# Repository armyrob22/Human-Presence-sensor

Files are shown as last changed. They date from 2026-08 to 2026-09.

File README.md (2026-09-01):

# Human-Presence-sensor
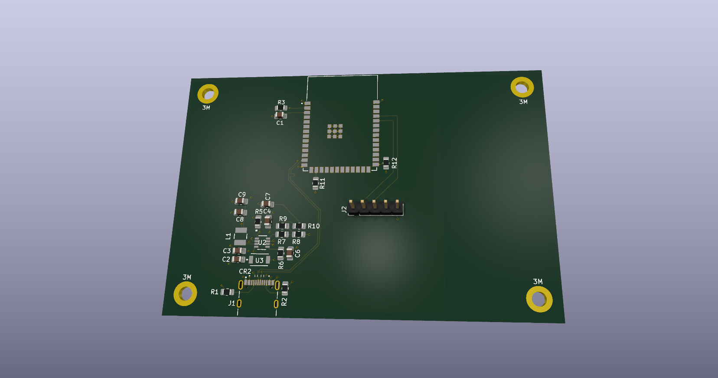
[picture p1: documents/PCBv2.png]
assembled board v2

This is my second version of this board. My first board had many errors and was basically unusable. The pin headers were not aligned once i got the boards. This made it impossible to use the esp32 dev board I had. The biggest failure was the fact that i misplaced the USB type C connector. It was not close enough to the edge for me to plug in a power cable. This design puts the ESP32 on the PCB and lets just the mmWave 24Ghz radar board plug into a pin header. This design forced me to learn how to really design a buck converter circuit so i can take the 5V USB input power and drop it down to 3.3V required for the MCU. I took it a step further and I really drilled down on learning the physic's and the equations to derive what you need for a buck converter.

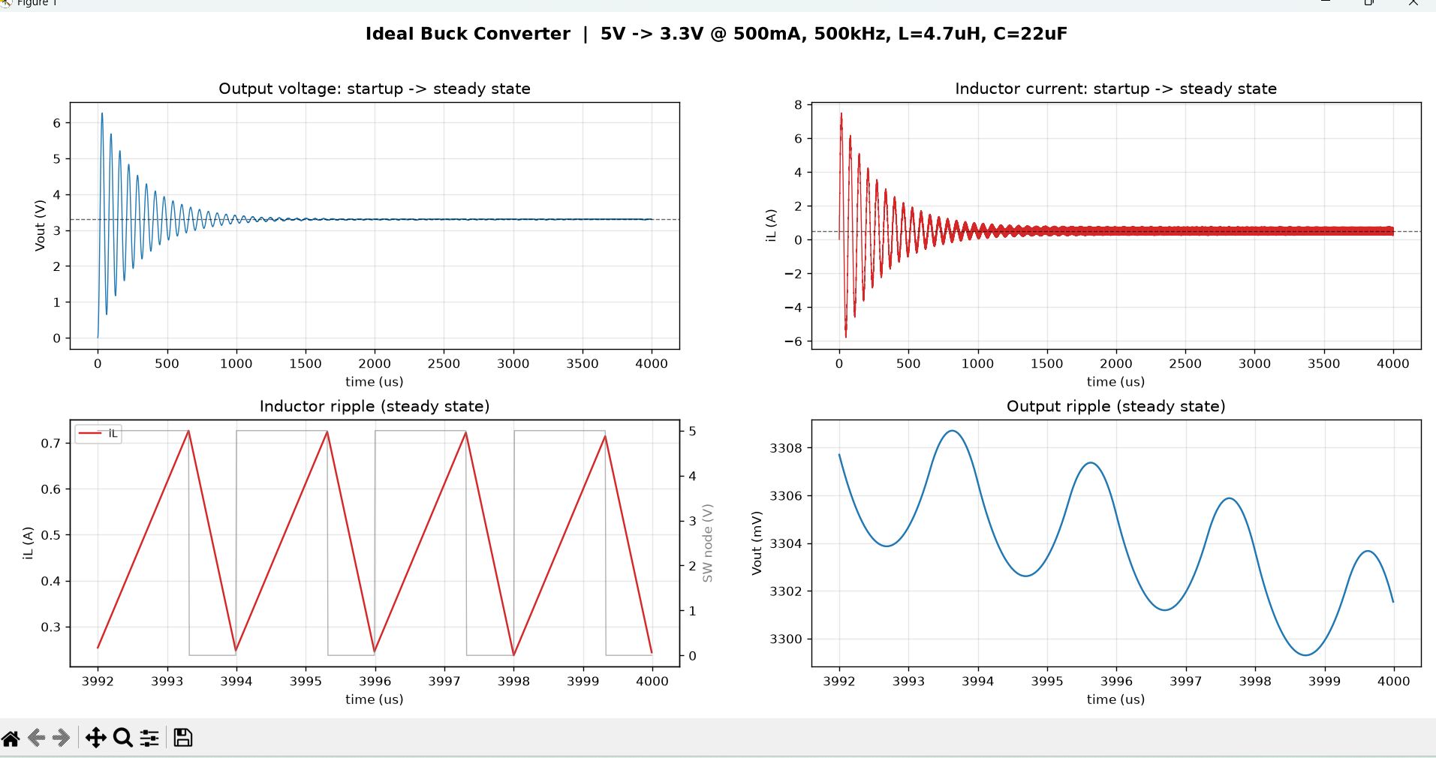
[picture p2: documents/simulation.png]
python simulation

This is the result of my python script running a simulation of my chosen buck converter. I ran several different versions to see if my inductor sizing was correct. The reference design I used for most of my layout turned out to be really good for my given circuit. This is why i chose a 4.7uH inductor for my design. Even though this is my project and my own board I tried to treat it with the same care I will bring to the work place when I get to design other boards. The next big piece of the buck converter was to figure out the feedback sense resistor values required. My converter has a reference voltage of 0.8v. This means the formula I used is
Vout = Vref × (1 + R1/R2)
Vref = 0.8V, R2 = 12.7k, R1 = 40.2k
Vout = 0.8 × (1 + 40.2/12.7) = 3.33V
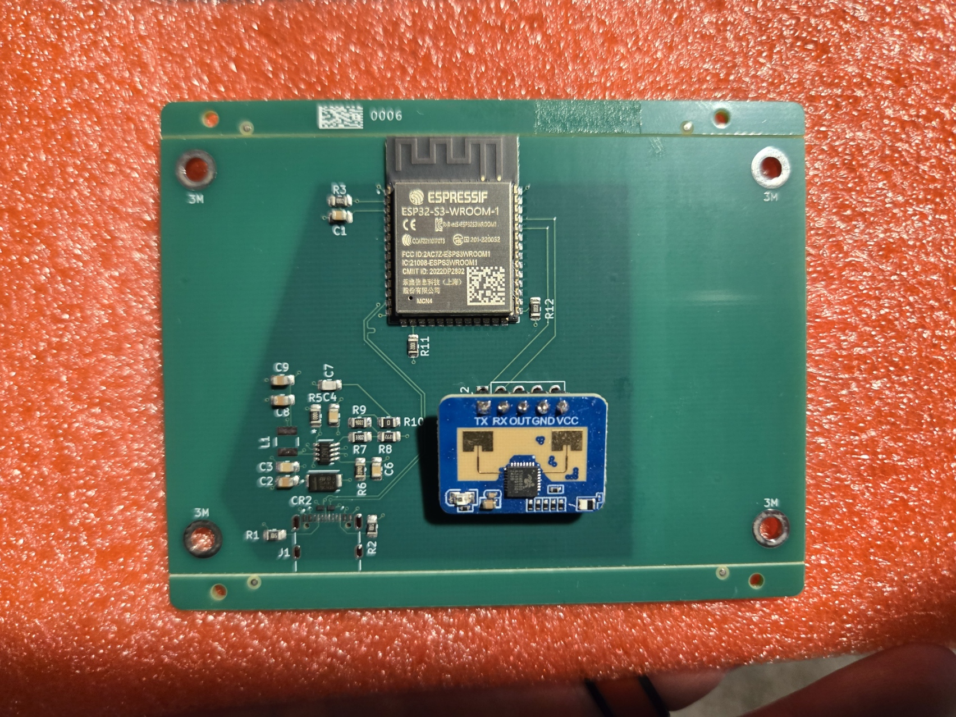
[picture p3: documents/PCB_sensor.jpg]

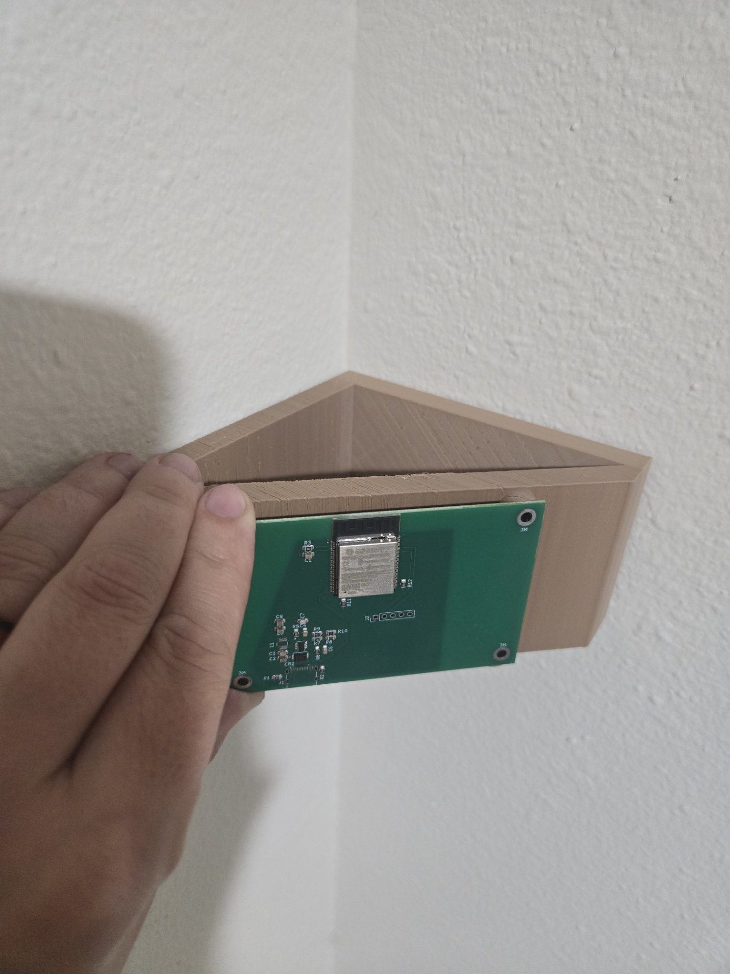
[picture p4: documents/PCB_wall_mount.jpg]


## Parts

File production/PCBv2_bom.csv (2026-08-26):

Designator | Footprint | Quantity | Value | LCSC Part #
C1 | 0805 | 1 | 1uF
C2, C8, C9 | 0805 | 3 | 22uF
C3, C4, C6 | 0805 | 3 | 0.1uF
C7 | 0805 | 1 | 33pF
CR1, CR2 | CR_RCLAMP053_1XP6_SEM-L | 2 | RCLAMP0531TQTCT
J1 | SAMESKY_UJ20-C-H-G-SMT-1-P16-TR | 1 | UJ20-C-H-G-SMT-1-P16-TR
J2 | PinHeader_1x05_P2.54mm_Vertical | 1 | Conn_01x05_Pin
L1 | IND_DFE322520FD-4R7M=P2_MUR | 1 | 4.7uH
R1, R2 | 0805 | 2 | 5k1
R10 | 0805 | 1 | 0
R11, R12, R3 | 0805 | 3 | 10k
R5 | 0805 | 1 | 100k
R6 | 0805 | 1 | 20
R7 | 0805 | 1 | 33k
R8 | 0805 | 1 | 12k7
R9 | 0805 | 1 | 40k2
U1 | XCVR_ESP32-S3-WROOM-1-N4 | 1 | ESP32-S3-WROOM-1-N4
U2 | TSOT23-8_MPS | 1 | MP2315GJ-Z
U3 | SOD128_STM-L | 1 | SM6F6.0AY

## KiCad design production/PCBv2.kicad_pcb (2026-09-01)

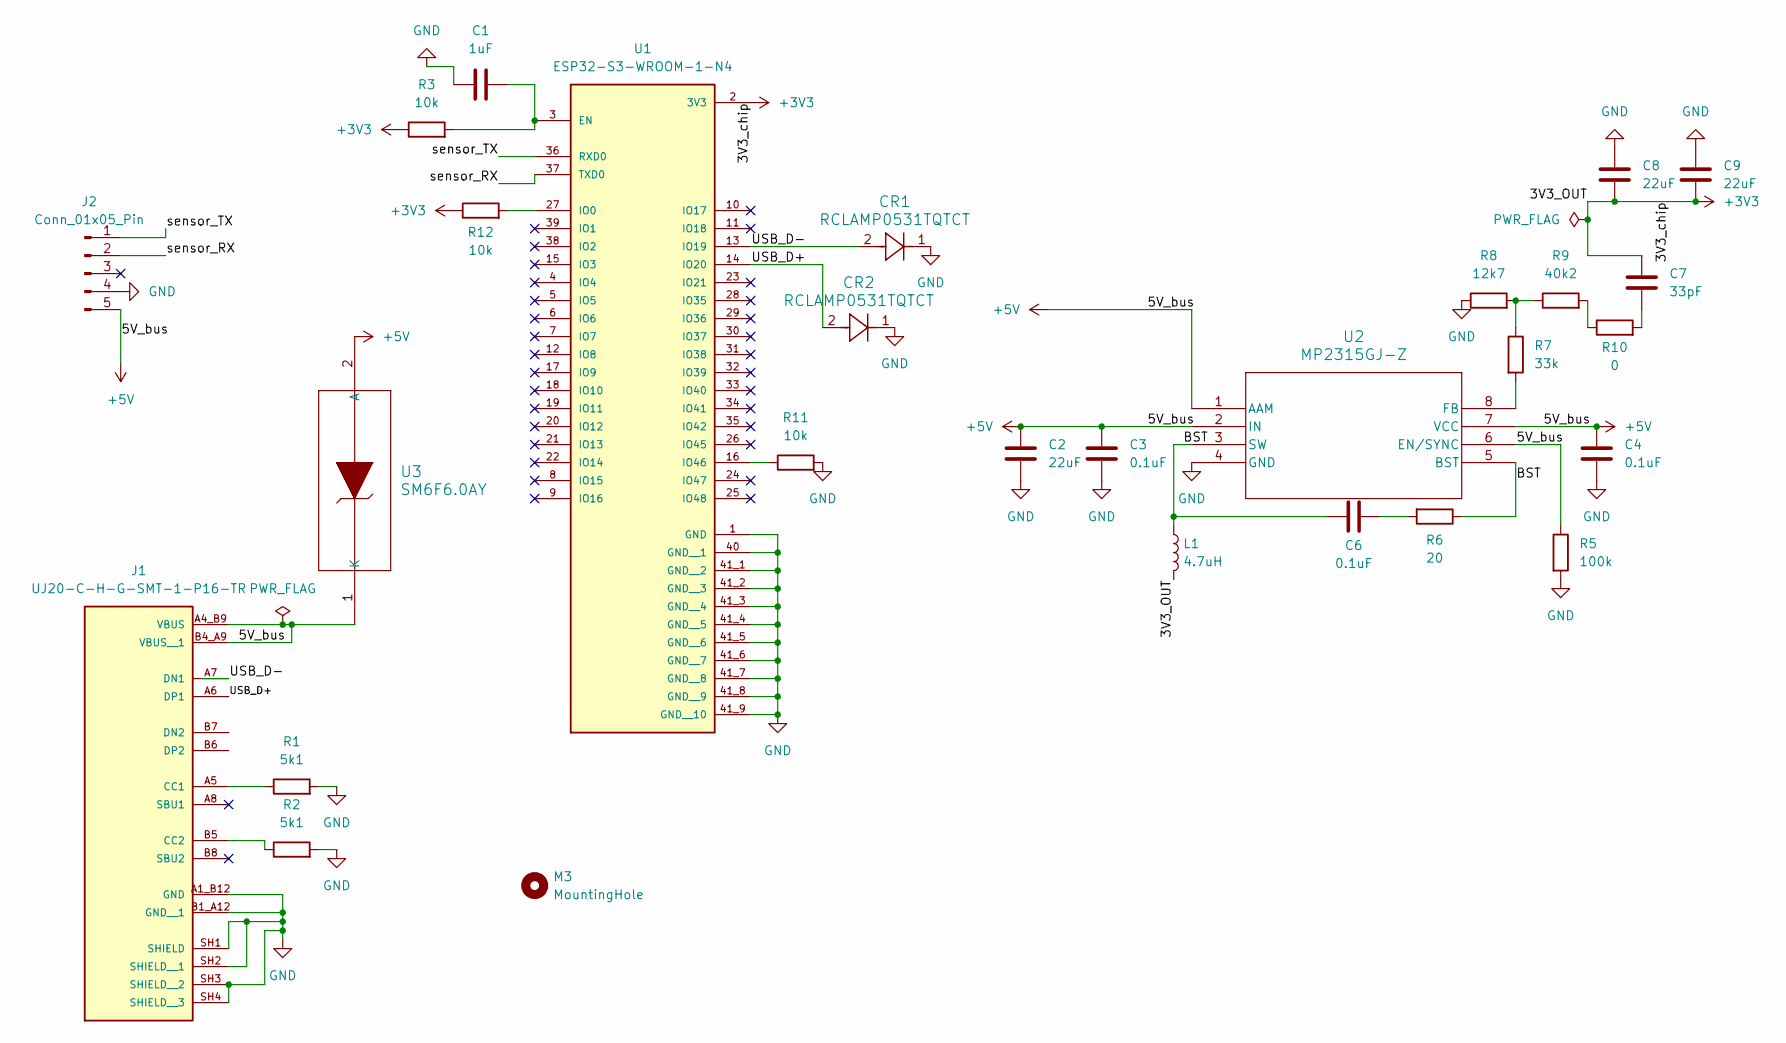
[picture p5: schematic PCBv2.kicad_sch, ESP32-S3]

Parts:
C1: 1uF; C_0805_2012Metric_Pad1.18x1.45mm_HandSolder
C2, C8, C9: 22uF; C_0805_2012Metric_Pad1.18x1.45mm_HandSolder
C3, C4, C6: 0.1uF; C_0805_2012Metric_Pad1.18x1.45mm_HandSolder
C7: 33pF; C_0805_2012Metric_Pad1.18x1.45mm_HandSolder
CR1, CR2: RCLAMP0531TQTCT; CR_RCLAMP053_1XP6_SEM-L
J1: UJ20-C-H-G-SMT-1-P16-TR; SAMESKY_UJ20-C-H-G-SMT-1-P16-TR; PARTREV 1.0
J2: Conn_01x05_Pin; PinHeader_1x05_P2.54mm_Vertical
L1: 4.7uH; IND_DFE322520FD-4R7M=P2_MUR
M3: MountingHole; MountingHole_3.2mm_M3_DIN965_Pad
R1, R2: 5k1; R_0805_2012Metric_Pad1.20x1.40mm_HandSolder
R3, R11, R12: 10k; R_0805_2012Metric_Pad1.20x1.40mm_HandSolder
R5: 100k; R_0805_2012Metric_Pad1.20x1.40mm_HandSolder
R6: 20; R_0805_2012Metric_Pad1.20x1.40mm_HandSolder
R7: 33k; R_0805_2012Metric_Pad1.20x1.40mm_HandSolder
R8: 12k7; R_0805_2012Metric_Pad1.20x1.40mm_HandSolder
R9: 40k2; R_0805_2012Metric_Pad1.20x1.40mm_HandSolder
R10: 0; R_0805_2012Metric_Pad1.20x1.40mm_HandSolder
U1: ESP32-S3-WROOM-1-N4; XCVR_ESP32-S3-WROOM-1-N4; PARTREV v1.0
U2: MP2315GJ-Z; TSOT23-8_MPS
U3: SM6F6.0AY; SOD128_STM-L

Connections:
+3V3: C7.2, C8.1, C9.1, L1.2, R3.1, R12.1, U1.2 (3V3)
+5V: C2.2, C3.2, C4.1, J1.A4_B9 (VBUS), J1.B4_A9 (VBUS__1), J2.5, R5.1, U2.1 (AAM), U2.2 (IN), U2.6 (EN/SYNC), U2.7 (VCC), U3.1 (K), U3.2 (A)
/BST: C6.1, L1.1, R6.1, U2.3 (SW), U2.5 (BST)
/USB_D+: CR2.2, J1.A6 (DP1), U1.14 (IO20)
/USB_D-: CR1.2, J1.A7 (DN1), U1.13 (IO19)
/sensor_RX: J2.2, U1.37 (TXD0)
/sensor_TX: J2.1, U1.36 (RXD0)
GND: C1.1, C2.1, C3.1, C4.2, C8.2, C9.2, CR1.1, CR2.1, J1.A1_B12 (GND), J1.B1_A12 (GND__1), J1.SH1 (SHIELD), J1.SH2 (SHIELD__1), J1.SH3 (SHIELD__2), J1.SH4 (SHIELD__3), J2.4, R1.2, R2.2, R5.2, R8.1, R11.2, U1.1 (GND), U1.40 (GND__1), U1.41_1 (GND__2), U1.41_2 (GND__3), U1.41_3 (GND__4), U1.41_4 (GND__5), U1.41_5 (GND__6), U1.41_6 (GND__7), U1.41_7 (GND__8), U1.41_8 (GND__9), U1.41_9 (GND__10), U1.41_10, U1.41_11, U1.41_12, U1.41_13, U1.41_14, U1.41_15, U1.41_16, U1.41_17, U1.41_18, U1.41_19, U1.41_20, U1.41_21, U2.4 (GND)
unnamed: C6.2, R6.2
unnamed: C7.1, R10.2
unnamed: J1.A5 (CC1), R1.1
unnamed: J1.B5 (CC2), R2.1
unnamed: R7.1, R8.2, R9.1
unnamed: R9.2, R10.1
unnamed: C1.2, R3.2, U1.3 (EN)
unnamed: R12.2, U1.27 (IO0)
unnamed: R11.1, U1.16 (IO46)
unnamed: R7.2, U2.8 (FB)

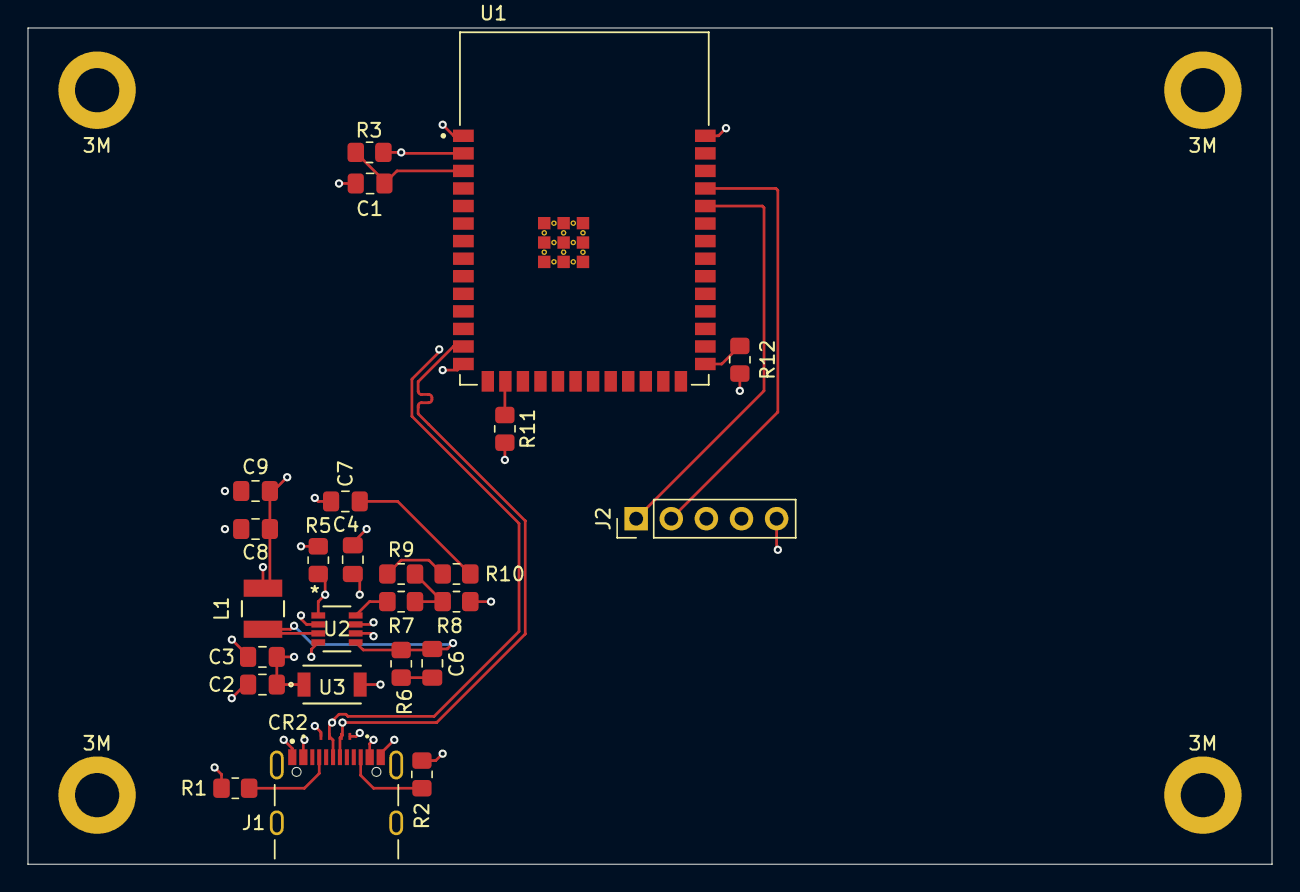
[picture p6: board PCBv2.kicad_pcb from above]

Board: 4 copper layers, 90.0 x 60.5 mm, 31 parts (0 on the bottom side), 18 nets.

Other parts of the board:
3M, 3M#2, 3M#3, 3M#4: MountingHole_3.2mm_M3_DIN965_Pad

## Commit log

2026-08-26 Add image to README for assembled board v2
2026-08-27 unzipped production files
    [PCBv2-B_Cu.gbl, PCBv2-B_Mask.gbs, PCBv2-B_Paste.gbp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]
2026-08-27 Update README with details on board version 2
    Added details about the second version of the board and improvements made.
2026-08-27 Add files via upload
    python simulation chart for buck converter.
2026-08-27 Enhance README with design challenges and simulation results
    Expanded the description of the board's design issues and improvements, including details about the USB connector placement and added a simulation image.
2026-08-27 Update README with project design insights
    Added details about the design challenges and learning experiences related to the second version of the board, including buck converter design and simulation results.
2026-09-01 Enhance README with buck converter design details
    Added detailed explanation of buck converter design and calculations.
2026-09-01 Add files via upload
    Kicad files
    [PCBv2.kicad_pcb, PCBv2.kicad_sch]
2026-09-01 Add PCB images to README
    Added images of the PCB layout for the buck converter project.
